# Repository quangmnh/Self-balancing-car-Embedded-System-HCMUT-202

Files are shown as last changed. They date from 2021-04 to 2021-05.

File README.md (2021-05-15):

# Abstract

We are making a Self-balancing robot taking inspiration from Wouter Klop's project

https://gitlab.com/kloppertje/balancingrobot

# Weekly Plan

## Week 20

- Calculate:
  + Torque
  + MPU-6050 returned value processing  
  + Body balancing factor (Applied mechanics lul)
- State machine
- Re-design some body part (da battery case, may need to ask Mr.Vỹ)..
- Print :
  + Battery Case (for next week when we receive the battery pack)
- Source code:
  + Clean up Mr. Klop's source code
  + Modularize them for easier report effort
- Hopefully make it run for da first time

## Week 19

- Calculation
  + Torque
  + MPU-6050 returned value processing  
  + Body balancing factor (Applied mechanics lul)
  + ~~Battery consumpstion and motor performance~~
- State machine 
- Re-design some body part (da battery case, may need to ask Mr.Vỹ).
- ~~Get PCB and assemble all parts ~~
- Print :
  + ~~Frame~~
  + ~~Wheel~~
  + Battery Case (for next week when we receive the battery pack)

## Week 16

- Calculation
  + Torque
  + MPU-6050 returned value processing  
  + Body balancing factor (Applied mechanics lul)
- State machine
- Re-design some body part.
- Get PCB and assemble all parts 
- Initiate the report.

## Week 15

- ~~Prototyping some body part for experiment.~~
- ~~Enlisting full electrical components with their price tag.~~
- ~~Buy the electrical components~~
- Initial calculation
  + Torque
  + ~~Power consumption~~
  + MPU-6050 returned value processing  
  + Body balancing factor (Applied mechanics lul)
- Re-design some body part.
- ~~PCB order (JLCPCB maybe)~~

# Expenditure and Notes

https://docs.google.com/spreadsheets/d/1sYImMAOnU2ea2EhUiEneGWEZ3-_E23mFMH0feFGn73Y/edit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

# Contents

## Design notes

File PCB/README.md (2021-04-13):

This folder contains KiCad (5.0.0) design files for the BalancingRobot PCB. 

# Features
* Supports both DRV8825 and A4988 based stepper drivers. Should also be compatible with TMC2100 (with settings configurable via ESP32), not tested yet though.
* Supported voltage: ~7 - 24V (2-6S LiPo/Li-ion)
* Digital current control of steppers (you'll need to desolder the potmeter and add a wire)
* Dynamic microstep switching, allowing for insane speeds
* Connections: 
	- Digital RC receiver (I use IBus / FlySky protocol), J5 upper row
	- Servo, J5 middle row. In case you want to add an arm for self righting :).
	- Digital LED (Neopixel / WS2812B etc), J5, lower row
	- All unused ESP32 pins are broken out (including I2C), for further use and development (J2)
	- Power input (J3). Allows for both a screw clamp and direct wire soldering. I prefer the last, given the high power output of a LiPo in case something comes loose.
* Wireless parameter tuning and data plotting. Makes tuning the controllers a lot easier
* Websocket communication for real-time communication between ESP32 and browser
* Web interface via access point / WiFi network. SSID and key can be set via web interface.

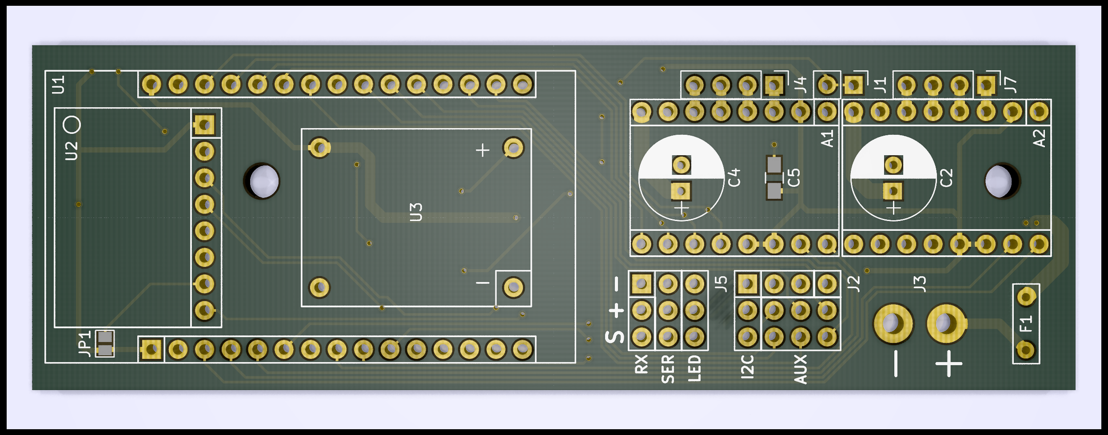
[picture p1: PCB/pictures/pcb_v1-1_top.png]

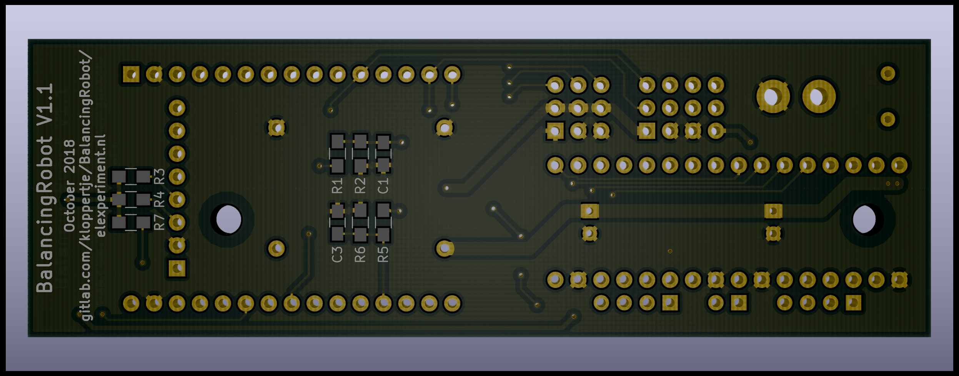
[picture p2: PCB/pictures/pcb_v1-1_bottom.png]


# Assembly
Assembly is quite straightforward. For those who like some instructions, here goes. For the ones that don't like to follow instructions: that's ok, but please read the last instruction about adjusting the buck converter voltage.

1. Start with the SMD components on the bottom side. First, pre-tin one pad, then place the SMD component while reheating the first pad. Finally, solder the second pad. C5 is not mounted.
2. Next, mount the voltage regulator module U3. Use some wires to connect the 4 pads to the PCB.
3. Place the IMU (U2) with the angled male and female headers. Make sure that the IMU is rigidly mounted. If you don't, the IMU might for example vibrate during operation, causing unstable behaviour. See below pictures for clarification.
4. Add all female headers (J1, J4, J7, and for the stepper driver and ESP32 modules). Optionally, place some headers on J5 and J2 if you like.
5. Finally, place C2, C4 and F1.

IMPORTANT: adjust the voltage regulator to 5V BEFORE inserting any modules. By default, the voltage regulator is set to a higher voltage, and if you don't adjust it, you'll fry some components. 

IMU mounting
<p float="left">
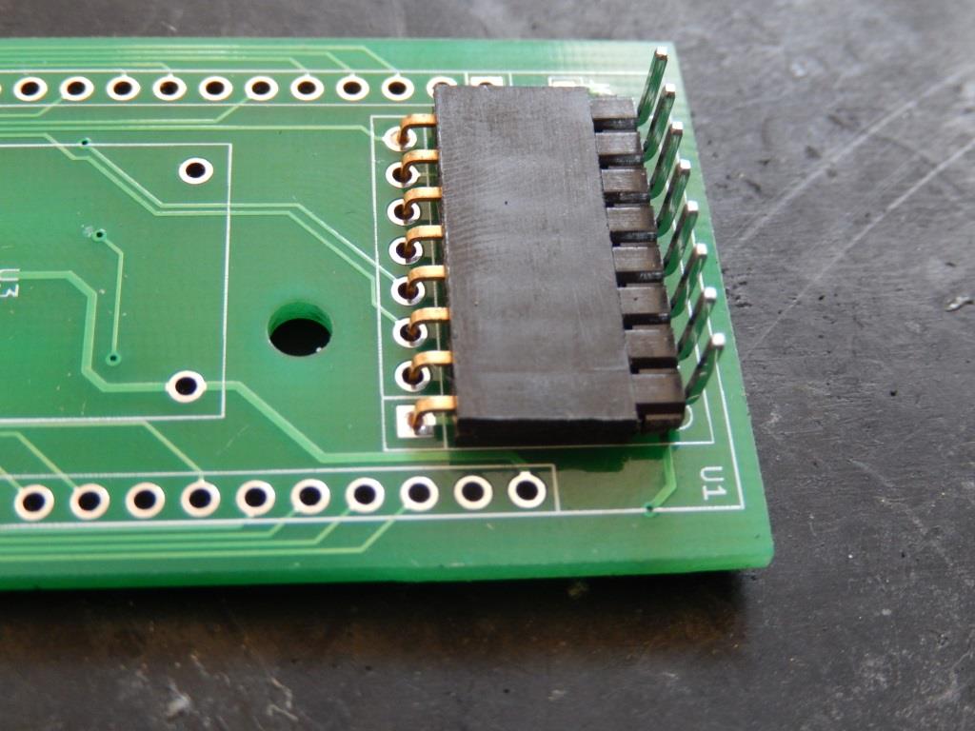
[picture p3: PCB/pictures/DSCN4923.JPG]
  
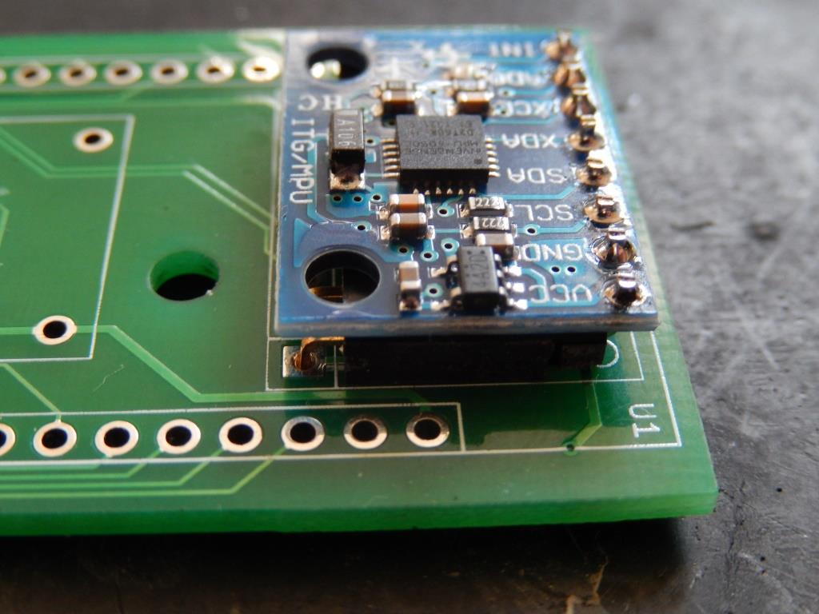
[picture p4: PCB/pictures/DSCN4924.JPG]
   
</p>

In the end, the PCB should look something like this
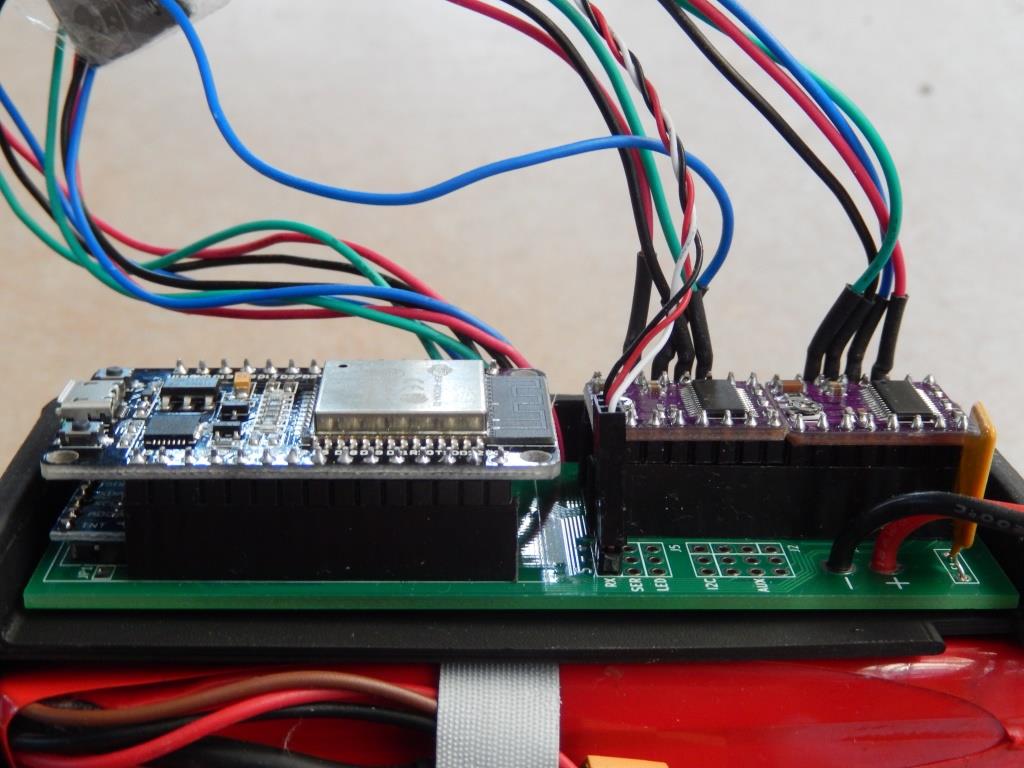
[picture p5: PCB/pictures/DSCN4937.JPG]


## Advanced
Some optional improvements are listed here, which are not required for basic operation. 

You can de-solder the current adjustment potentiometer on the stepper driver breakout boards. Add a wire to the wiper terminal, and connect the (two) wires to J4. Current can then be adjusted via the web interface. Or, get creative, and implement some current saving functionality.

For better performance, you can tie the decay mode pin of the DRV8825 to VCC, setting it in fast mode. The DRV8825 sometimes skips steps in slow/mixed decay mode. Below picture illustrates both improvements.

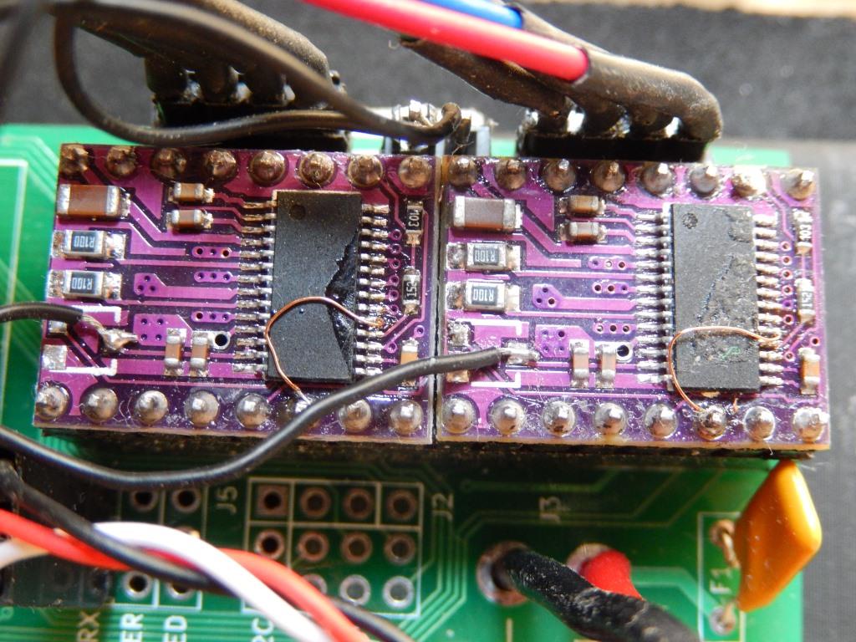
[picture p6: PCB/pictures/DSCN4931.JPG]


## Auxiliary header
Connector J2 has a grid of 12 pins (3x4), with some general pins broken out, together with all unused ESP32 IO pins. See the close-up of the header below. Pin numbering in this picture is used in the table below to identify pins.

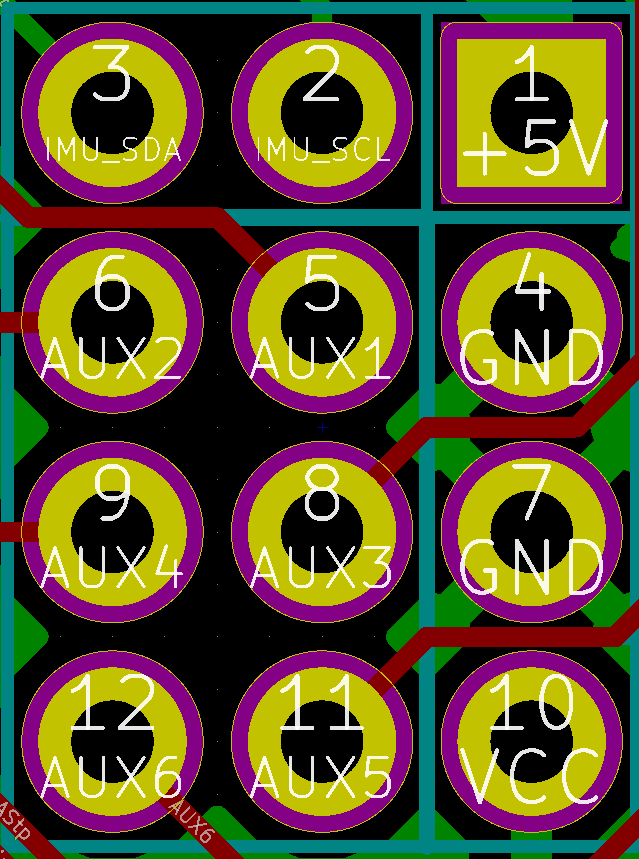
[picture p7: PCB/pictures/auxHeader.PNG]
Auxiliary header pinout
//


| Pin # | Name | ESP32 pin |
|---|---|---|
| 1 | 5V | Vin |
| 2 | IMU_SCL | D22 |
| 3 | IMU_SDA | D21 |
| 4 | GND | GND |
| 5 | AUX1 | D32 |
| 6 | AUX2 | D33 |
| 7 | GND | GND |
| 8 | AUX3 | D35 |
| 9 | AUX4 | D26 |
| 10 | VCC | 3V3 |
| 11 | AUX5 | D39 |
| 12 | AUX6 | D36 |

# BOM
Applicable for v1.1. v1.0 doesn't have R7.

| Qty | Reference(s) | Value |
|-----|---|---|
| 2 | A1, A2 | DRV8825 / A4988 stepper driver breakout  |
| 2 | C1, C3 | 1u capacitor, 0805 SMD |
| 2 | C2, C4 | 100u elco |
| 1 | C5 | 100n capacitor, not placed |
| 1 | F1 | Polyfuse |
| 1 | J1 | Female header, cut to size |
| 1 | J2 | N/A, solder whatever you like here |
| 1 | J3 | Screw terminal, or solder wires directly |
| 2 | J4, J7 | 4 pin (fe)male header, cut to size |
| 1 | J5 | Male header, cut to size |
| 6 | R1, R2, R3, R4, R6, R7 | 3k3 resistor, 0805 SMD |
| 1 | R5 | 100k resistor, 0805 SMD |
| 1 | U1 | ESP32 devKit module, 30 pins |
| 1 | U2 | MPU6050 breakout, 8 pins |
| 1 | U3 | Buck converter module |

Additionally, you'll need a pair of 8 pin male/female angled headers, for mounting the IMU. For mounting the ESP32 and stepper driver modules, you'll need 2 times 15 and 16 pin female headers (4 in total).

Some examples of the modules:
* [ESP32 Devkit V1 module, 30 pins](https://www.aliexpress.com/item/ESP32-Development-Board-WiFi-Bluetooth-Ultra-Low-Power-Consumption-Dual-Core-ESP-32-ESP-32S/32802431728.html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)
* [DRV8825 stepper driver](https://www.aliexpress.com/item/Free-shipping-10pcs-lot-3D-Printer-StepStick-DRV8825-Stepper-Motor-Drive-Carrier-Reprap-4-layer-PCB/32292074706.html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)
* [MPU6050 IMU](http://www.aliexpress.com/item/GY-521-MPU-6050-MPU6050-Module-3-Axis-analog-gyro-sensors-3-Axis-Accelerometer-Module/32340949017.html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)
* [Buck converter](https://www.aliexpress.com/item/10PCS-Mini-3A-DC-DC-Converter-Step-Down-Module-Adjustable-3V-5V-16V-Power-for-RC/32639738406.html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)

# Issues
For PCB version 1.0, the + and - signs of the RX/Servo/LED indicator are swapped. The pinout is correct though. To be clear, the order (from right to left) is -, +, and signal. This has been solved in v1.1.

# Change history
## v1.0 
Initial version
## v1.1
* Increased track width of 5V and 24V traces
* Added second via in 24V trace, or rather added trace to second via which wasn't there in v1.0
* Swapped + and - symbols on silkscreen close to RX header 
* Added a 10k pull-up on the stepper driver enable. In v1.0, no pull-up is present, meaning the steppers are enabled if the ESP32 isn't running. No big deal, but somewhat neater to disable steppers if the ESP32 isn't running.
## v1.2
* Added optional 100k RX pulldown resistor
* Added optional 5V filtering cap (might be useful if for example some Neopixels are connected to 5V line)
* Added some markings for the buck converter, clarifying the mounting direction
* Added connections for (fused) battery voltage (J6)

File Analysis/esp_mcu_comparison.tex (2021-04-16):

\documentclass[tikz,table,border=2mm]{standalone}
\usepackage{PTSansNarrow}
\usepackage[T1]{fontenc}
\usepackage{array,tabularx}
\usepackage[most]{tcolorbox}

\begin{document}

\rowcolors{1}{black!30}{white}
\begin{tcolorbox}[enhanced, notitle, clip upper, fontupper=\sffamily,%
    tabularx={>{\cellcolor[gray]{.5}\color{white}}r%
              >{\centering\arraybackslash}X%
              >{\centering\arraybackslash}X}]
Aspect  & NodeMCU wroom     & ESP32 wrover \\
Size     & 25.4*48.26*3mm( 0.2mm ) & 18.00±0.10)×(31.40±0.10)×(3.30±0.10) \\
Interface       & FC-4                               & PCIe x4 \\
Drive Units     & 150$\times$15 RPM disks            & 2$\times$80gig\\
Data Protection & Mirroring                          & Mirroring\\
Power           & 33.372 kWh/yr                      & 114 kWh/yr\\
SPC-1 I0PS      & 24.998                             & 86.127
\end{tcolorbox}
\end{document}

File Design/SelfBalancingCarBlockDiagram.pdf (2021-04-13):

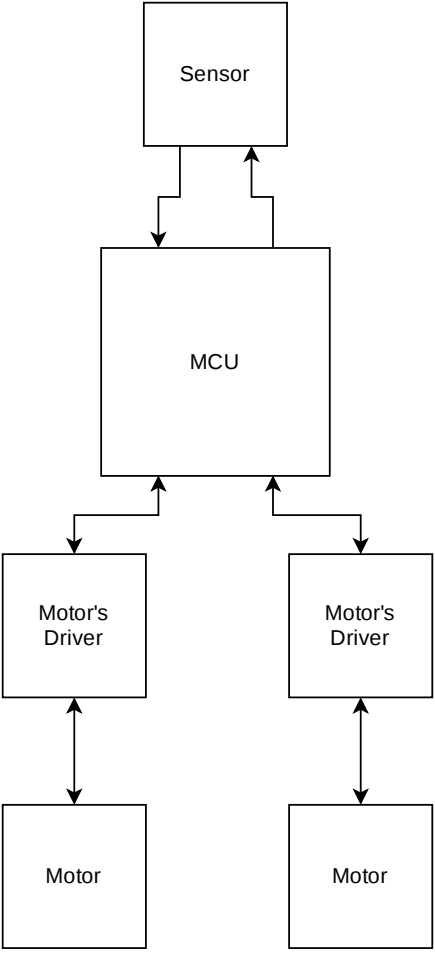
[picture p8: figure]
MCU; Motor; Motor's Driver; Sensor

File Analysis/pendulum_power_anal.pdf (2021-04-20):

VIETNAM NATIONAL UNIVERSITY - HO CHI MINH CITY UNIVERSITY OF TECHNOLOGY
FACULTY OF COMPUTER SCIENCE & ENGINEERING

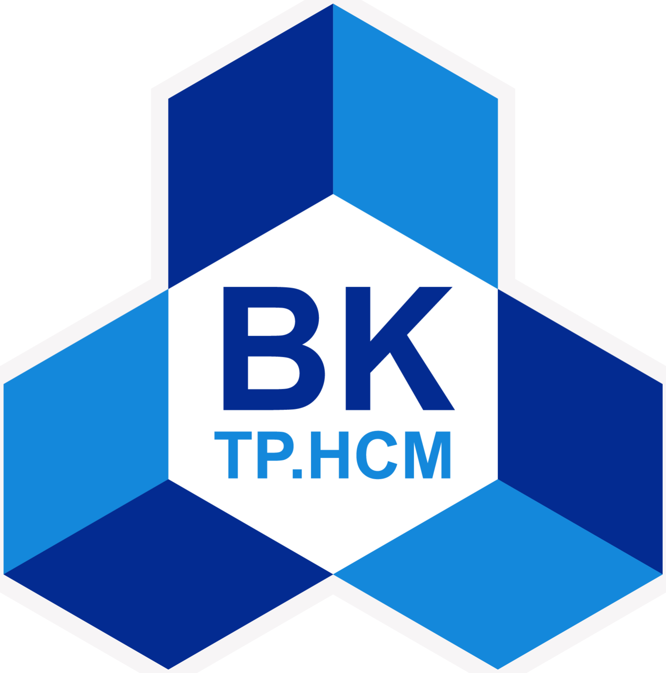
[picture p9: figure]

## EMBEDDED SYSTEM

## Analysis

# POWER & PERFORMANCE

Instructor: | Pham Hoang Anh
Student: | Nguyen Tran Quang Minh | - 1811083

HO CHI MINH CITY, April 2021

Ho Chi Minh City University of Technology Faculty of Computer Science & Engineering

## Contents

1 Power | 2
Embedded System - 2020-2021 | Page 1/3

## 1 Power

### 1.1 Datasheet information:

No. | Name | Description | Min | Max | Typical | Note
1. | ESP32 de-vkit | The operating voltage of ESP32 ranges from 2.3 V to 3.6 V. When using a single-power supply, the recommended volt-age of the power supply is 3.3 V | 500 mA | - | - | Average current in actual test is no more than 150 mA with 600 mA spike
2. | MPU6050 | The sensor has 3 dis-tinct feature and power consumption is based on what features are used in combination Gyroscope/Accelerome-ter/DMP | 3.6 mA | 3.9 mA | 3.6 mA | Look like only Gy-roscope is used
3. | Nema 17 | The motor operates in 2 phase, with rated voltage and currentin the datasheet, model KH42JM2B182A | 0.85 A | 0.9 A | 0.88 A | The stats in official datasheet and product mark is different so i take them as low/high values.

### 1.2 Calculation:

With the above stats, we can assume that the pair of motor will draw 0.88*2 =1.76 A per phase

and 3.52 A in total.

Therefore, we need about 4A current (at max) and about 3.7 A average. The battery we chose,

a 3-cell Lion battery with 30 C max discharge current and 2000 mAh capacity, merely meets the requirement. We expect it to sustain at least half an hour before recharge.

With some calculation, we can get the maximum performance of the Nema 17 stepper motor [1]:

M axSpeed =

V
2LImax · spr

(1)

M intimeperstep =

2LImax
V

(2)

Pmax = ImaxV | (3)

Hence, at nominal voltage (3.7*3 = 11.1 V), we get the result of 6.18 revolutions/s, 0.809 ms/step

and 9.77 W max power.

At max voltrage (4.2*3 = 12.6 V), we get 7.02 revolutions/s, 0.712 ms/step and 11.1 W max

power.

## References

[1] https://www.allaboutcircuits.com/tools/stepper-motor-calculator/

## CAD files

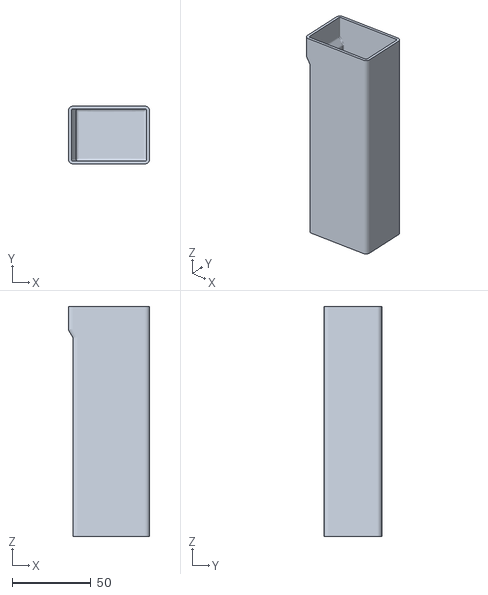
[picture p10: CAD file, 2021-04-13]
3dpart/battery-case/BatteryCase v1.stl
51.8 x 36.8 x 146.5

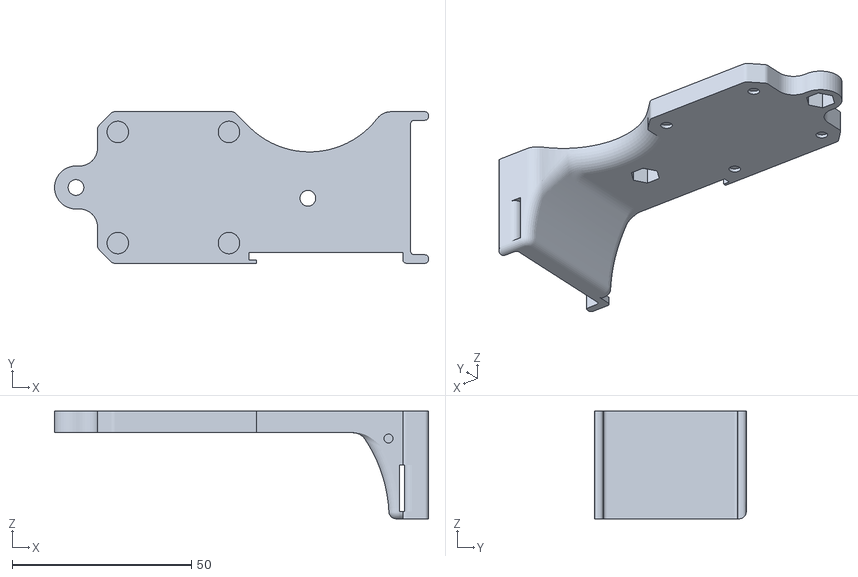
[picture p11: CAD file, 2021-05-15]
3dpart/frame/frameA1_mirror.stl
104.3 x 42.3 x 30.0

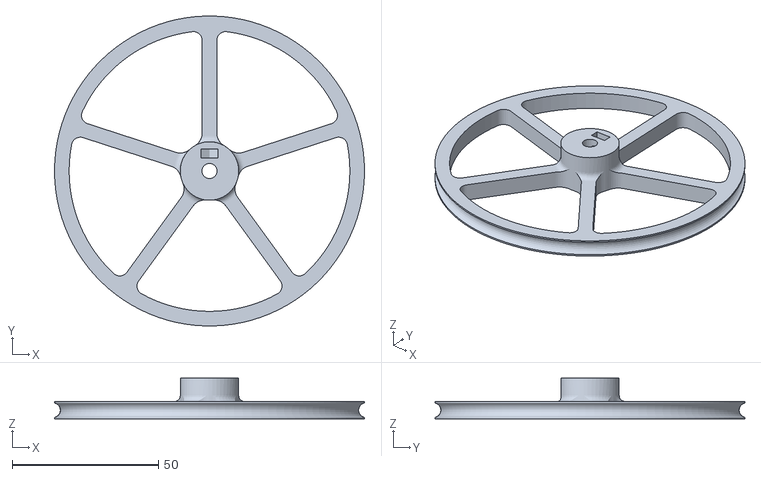
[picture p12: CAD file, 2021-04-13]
3dpart/wheel/Wheel v2.stl
106.0 x 105.9 x 14.0

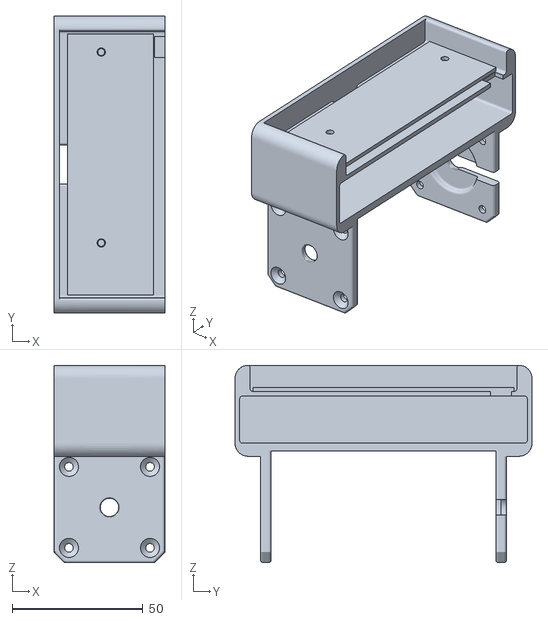
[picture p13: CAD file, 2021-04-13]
3dpart/frame/FrameB v10.stl
42.3 x 113.6 x 75.5

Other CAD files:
3dpart/frame/FrameA1.stl
3dpart/frame/FrameA2.stl
3dpart/battery-case/BatteryCase v1.f3d
3dpart/frame/FrameA v1.f3d
3dpart/frame/FrameB v10.f3d
3dpart/untitled.blend
3dpart/wheel/Wheel v2.f3d

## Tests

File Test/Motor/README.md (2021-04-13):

This folder contains the software source files, written for an ESP32 using the Arduino framework. PlatformIO is used as environment, as it is very easy to use, and provides somewhat more advanced functions, compared to the very basic Arduino IDE. 

# Build environment
For setting up PlatformIO, see https://docs.platformio.org/en/latest/ide/atom.html or https://docs.platformio.org/en/latest/ide/vscode.html. I use Atom myself, but both IDEs will work fine. 

Clone the repository. I strongly advice to not download the source files as a zip package, but to use Git properly. The code is very experimental, and will be often updated.

Once installed, go to PlatformIO home in the IDE. In there, click "Open Project", and navigate to the location where you cloned the repository. Select the "Software" folder, and then click "Open "Software"". 

Open src/main.cpp. You should now be able to combile (ctrl+alt+B).

# Uploading firmware
For uploading, I strongly prefer OTA, as this works very nice in PlatformIO.  

## Serial port
For the first upload, you'll need to upload via USB / the serial port. In platformio.ini, state the COM port under which the ESP32 module is connected (uncomment the line with an IP address / host name), for example 
upload_port = COM3. 
; upload_port = balancingRobot.local

Hit the upload button. Currently, the auto reset functionality of the ESP32 module doesn't seem to work, see Issue #10. So, once the message "Serial port COMx" appears, press the enable and boot buttons on the module. First release the boot button, then the enable button. You might have to try a few times. Luckily, once succeeded with the serial upload, you can use OTA upload.

## OTA upload
When the ESP32 boots, it's IP address is printed. In platformio.ini, fill in this IP address under upload_port. Or, even better, use the hostname balancingRobot.local. This means you don't have to mess around with IP addresses. Make sure to be connected to the same WiFi network as the ESP32, and hit upload.

## File system
Initially, or when changing the web page files, you need to upload the file system. To do so, open a terminal within the PlatformIO environment, and run:
platformio run --target uploadfs

This will upload all content of the data folder to the ESP32 flash memory (either via the serial port or OTA).

# WiFi connection
After flashing, the ESP32 will start an access point (AP), named balancingRobot. The default key is "turboturbo". Once connected, open the balancingRobot web configuration page. Here, among others, you can change the WiFi options. Under "WiFi configuration", enter the SSID and key of your home network, change the selector from "AP" to "SSID", and click the "set" button, followed by the "reboot" button. If all goes well, the ESP32 will now connect to your home network. 

If you are using an IP address instead of host name, don't forget to check the ESP32's IP address, and update this in platformio.ini. It is probably wise to assign a fixed IP address to the ESP32 (via the router).

If the home network cannot be found, the AP will be started.

# Web page editor
hostName.local/edit

User/pass: admin, admin

Be aware though that changes here are not kept on your PC, so make sure to copy and paste everything.

# Plotting signals
hostName.local/plotTest.htm

To be merged into index.htm

For this to work, first load plotTest.htm, then index.htm. This allows to view signals, while simultaneously adjusting parameters. 

# Wifi control
For a slider based web page to control your robot

hostName.local/control.htm

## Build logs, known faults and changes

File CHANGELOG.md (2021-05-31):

## [0.0.5] - 2021-05-15

### Added
- Test project for individual motor test (seem to be not working at 11.1 volts input), at
> test/Motor
- mirrored stl of frameA1_mirror.stl at 
> 3dpart/frame
- GCODE files for printing at ABC Solutions, at
> 3dpart/GCODE

## [0.0.4] - 2021-04-20

### Nice
### Added
- Power and performance analysis (to be updated). 

## [0.0.3] - 2021-04-16

### Added

- PCB gerber files for PCB order.
- x3g for printing body part.

## [0.0.2] - 2021-04-15

### Added

- Analysis folder initiated, comparison of ESP MCUs.

## [0.0.1] - 2021-04-13

### Added

- Hardware design as stl files, for 3d printed.
- PCB design using KiCAD
- Initial code for programming the development board.
- The block diagram of the system

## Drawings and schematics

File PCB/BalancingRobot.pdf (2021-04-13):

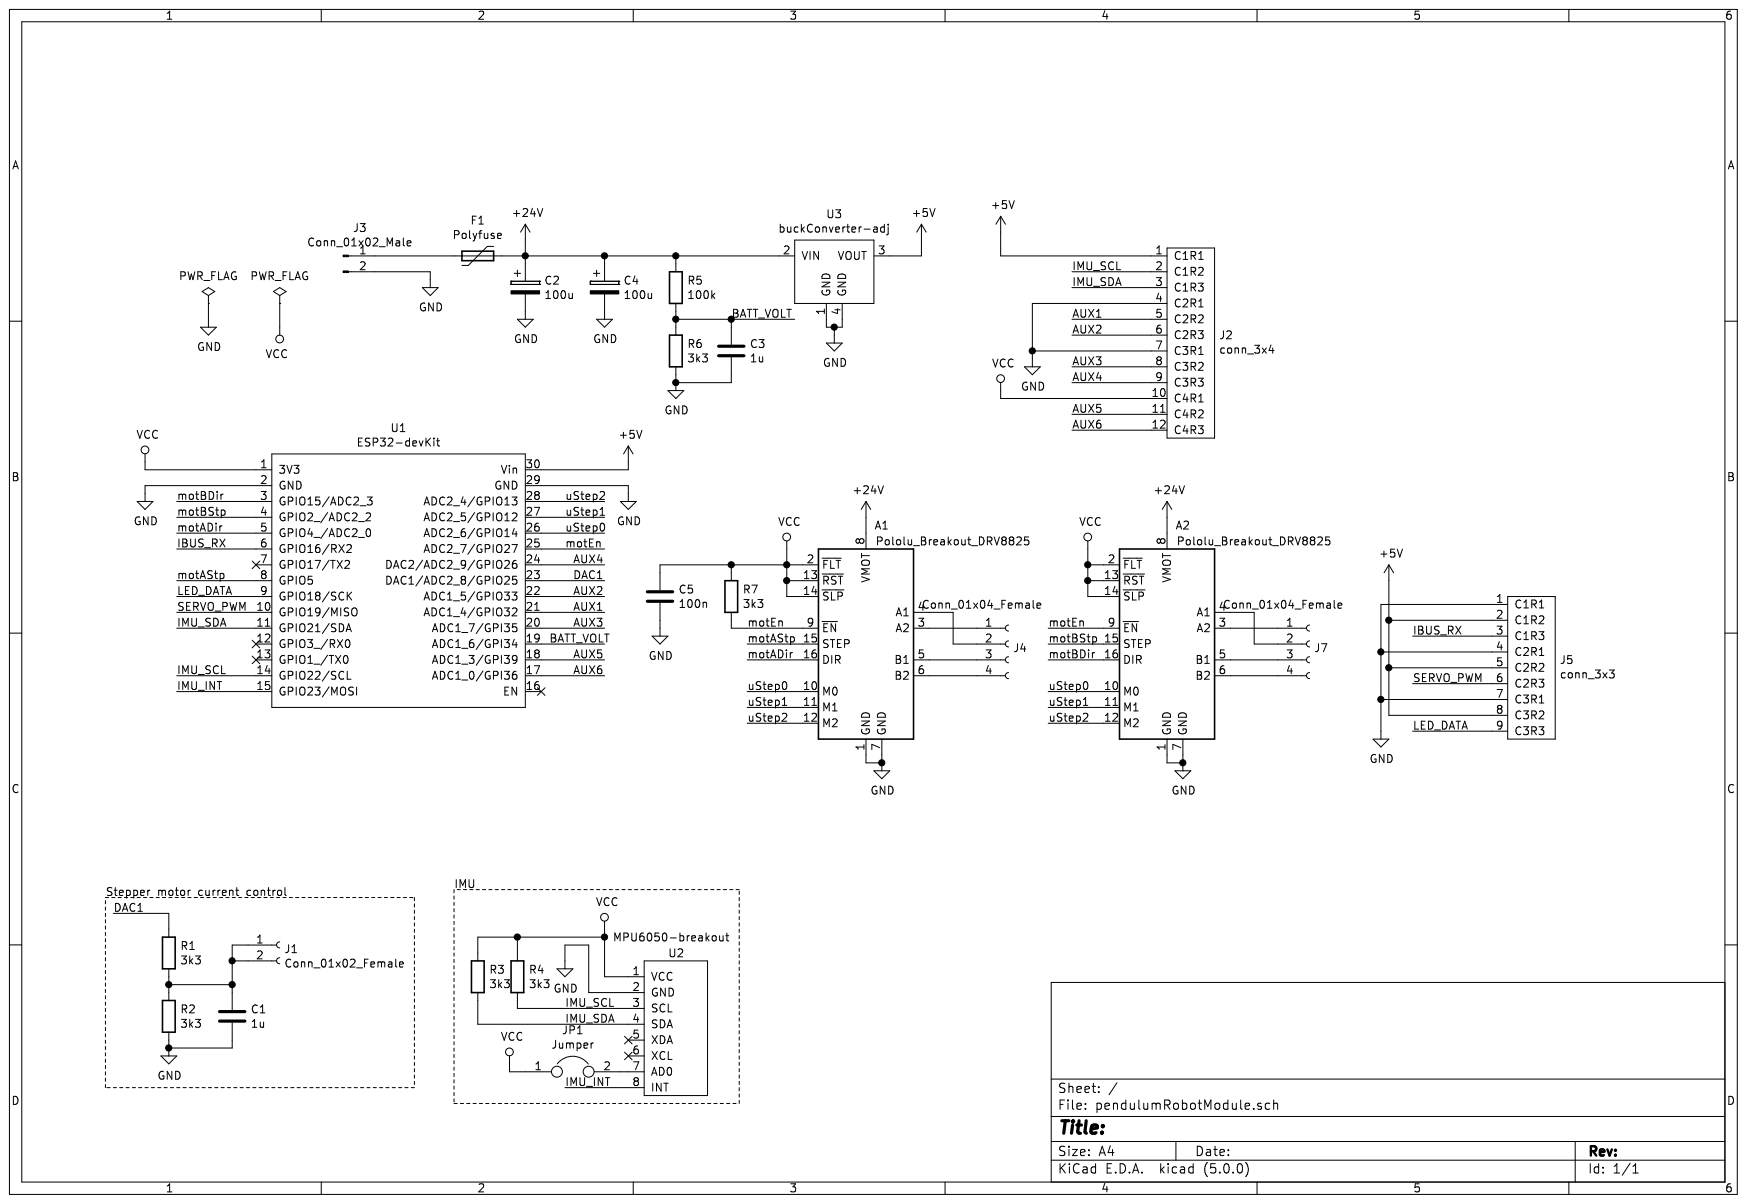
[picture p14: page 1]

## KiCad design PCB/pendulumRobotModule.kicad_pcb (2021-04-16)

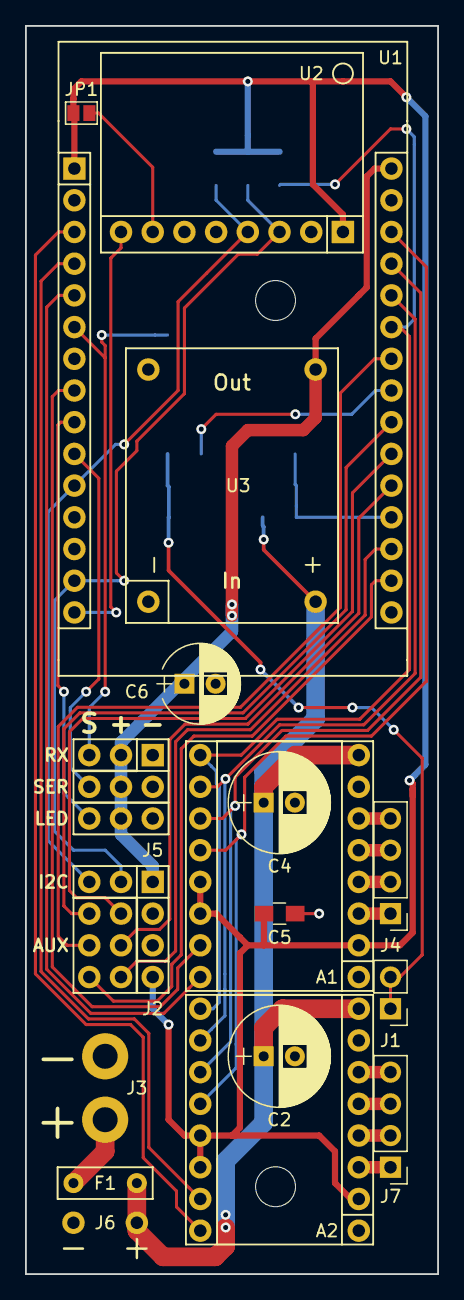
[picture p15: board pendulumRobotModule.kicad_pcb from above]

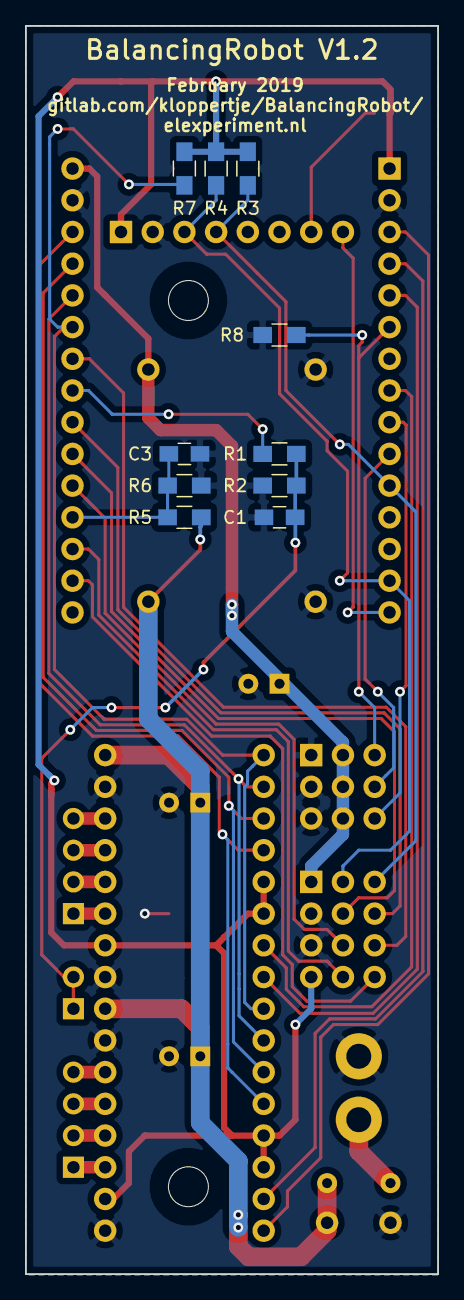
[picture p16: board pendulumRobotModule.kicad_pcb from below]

Board: 2 copper layers, 33.0 x 100.0 mm, 28 parts (10 on the bottom side), 37 nets.

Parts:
A1, A2: Pololu_Breakout_DRV8825; DRV8825-breakout
C1, C3: 1u; C_0805_HandSoldering
C2, C4: 100u; CP_Radial_D8.0mm_P2.50mm
C5: 100n; C_0805_HandSoldering
C6: 470u; CP_Radial_D6.3mm_P2.50mm
F1: Polyfuse; polyfuse-5.08mm
J1: Conn_01x02_Female; Socket_Strip_Straight_1x02_Pitch2.54mm
J2: conn_3x4; pinHeader_3x4
J3: Conn_01x02_Male; wirePad-2x-2mm
J4, J7: Conn_01x04_Female; Socket_Strip_Straight_1x04_Pitch2.54mm
J5: conn_3x3; pinHeader_3x3
J6: Conn_01x02_Male; pinHeader_2x1_5.08mm
JP1: Jumper; GS2
R1, R2, R3, R4, R6, R7: 3k3; R_0805_HandSoldering
R5, R8: 100k; R_0805_HandSoldering
U1: ESP32-devKit; ESP32-devkit-30p
U2: MPU6050-breakout; MPU6050-breakout-angledHeader
U3: buckConverter-adj; buck-converter-adj

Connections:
+5V: C6.1, J2.1, J5.2, J5.5, J5.8, U1.30, U3.3
+24V: A1.8, A2.8, C2.1, C4.1, F1.1, J6.1, R5.1, U3.2
/AUX1: J2.5, U1.21
/AUX2: J2.6, U1.22
/AUX3: J2.8, U1.20
/AUX4: J2.9, U1.24
/AUX5: J2.11, U1.18
/AUX6: J2.12, U1.17
/BATT_VOLT: C3.1, R5.2, R6.1, U1.19
/DAC1: R1.1, U1.23
/IBUS_RX: J5.3, R8.1, U1.6
/IMU_INT: U1.15, U2.8
/IMU_SCL: J2.2, R4.2, U1.14, U2.3
/IMU_SDA: J2.3, R3.2, U1.11, U2.4
/LED_DATA: J5.9, U1.9
/SERVO_PWM: J5.6, U1.10
/motADir: A1.16, U1.5
/motAStp: A1.15, U1.8
/motBDir: A2.16, U1.3
/motBStp: A2.15, U1.4
/motEn: A1.9, A2.9, R7.2, U1.25
/uStep0: A1.10, A2.10, U1.26
/uStep1: A1.11, A2.11, U1.27
/uStep2: A1.12, A2.12, U1.28
GND: A1.1, A1.7, A2.1, A2.7, C1.2, C2.2, C3.2, C4.2, C5.2, C6.2, J2.4, J2.7, J3.2, J5.1, J5.4, J5.7, J6.2, R2.2, R6.2, R8.2, U1.2, U1.29, U2.2, U3.1, U3.4
unnamed: A1.3, J4.1
unnamed: A1.4, J4.2
unnamed: A1.5, J4.3
unnamed: A1.6, J4.4
unnamed: A2.3, J7.1
unnamed: A2.4, J7.2
unnamed: A2.5, J7.3
unnamed: A2.6, J7.4
unnamed: C1.1, J1.1, J1.2, R1.2, R2.1
unnamed: F1.2, J3.1
unnamed: JP1.2, U2.7
VCC: A1.2, A1.13, A1.14, A2.2, A2.13, A2.14, C5.1, J2.10, JP1.1, R3.1, R4.1, R7.1, U1.1, U2.1

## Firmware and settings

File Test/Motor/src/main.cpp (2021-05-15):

/*
A high speed balancing robot, running on an ESP32.

Wouter Klop
wouter@elexperiment.nl
For updates, see elexperiment.nl

Use at your own risk. This code is far from stable.

This work is licensed under the Creative Commons Attribution-ShareAlike 4.0 International License.
To view a copy of this license, visit http://creativecommons.org/licenses/by-sa/4.0/
This basically means: if you use my code, acknowledge it.
Also, you have to publish all modifications.

*/
#include <Arduino.h>
#include <FlySkyIBus.h>
#include <WiFi.h>
#include <ESPmDNS.h>
#include <WiFiUdp.h>
#include <ArduinoOTA.h>
#include <Streaming.h>
#include <MPU6050.h>
#include <PID.h>
#include <AsyncTCP.h>
#include <ESPAsyncWebServer.h>
#include <WebSocketsServer.h>
#include <FS.h>
#include <SPIFFS.h>
#include <SPIFFSEditor.h>
#include <fastStepper.h>
// #include <par.h>
#include <Preferences.h>  // for storing settings

// Define parameter
#ifndef M_PI
  #define M_PI 3.14159265358979323846
#endif

// Define state variable
#define RUNNING 1
#define STANDBY 0
bool state = STANDBY;
// ----- Input method

// Driving behaviour
float speedFactor = 0.5;  // how strong it reacts to inputs, lower = softer (limits max speed) (between 0 and 1)
float steerFactor = 1.0;  // how strong it reacts to inputs, lower = softer (limits max speed) (between 0 and 1)
float speedFilterConstant = 0.9;  // how fast it reacts to inputs, higher = softer (between 0 and 1, but not 0 or 1)
float steerFilterConstant = 0.9;  // how fast it reacts to inputs, higher = softer (between 0 and 1, but not 0 or 1)

// PPM (called CPPM, PPM-SUM) signal containing 8 RC-Channels in 1 PIN ("RX" on board)
// Channel 1 = steer, Channel 2 = speed
#define INPUT_PPM
#define PPM_PIN 16  // GPIO-Number
#define minPPM 990  // minimum PPM-Value (Stick down)
#define maxPPM 2015  // maximum PPM-Value (Stick up)

// FlySkyIBus signal containing 8 RC-Channels in 1 PIN ("RX" on board)
// #define INPUT_IBUS

// ----- Type definitions
typedef union {
  struct {
    float val; // Float (4 bytes) comes first, as otherwise padding will be applied
    uint8_t cmd;
    uint8_t checksum;
  };
  uint8_t array[6];
} command;

// Plot settings
struct {
  boolean enable = 0; // Enable sending data
  uint8_t prescaler = 4;
} plot;

#define FORMAT_SPIFFS_IF_FAILED true

// ----- Function prototypes
void sendWifiList(void);
void parseSerial();
void parseCommand(char* data, uint8_t length);
void calculateGyroOffset(uint8_t nSample);
void readSensor();
void initSensor(uint8_t n);
void setMicroStep(uint8_t uStep);
void webSocketEvent(uint8_t num, WStype_t type, uint8_t * payload, size_t length);
void sendConfigurationData(uint8_t num);

void IRAM_ATTR motLeftTimerFunction();
void IRAM_ATTR motRightTimerFunction();

// ----- Definitions and variables
// -- Web server
const char* http_username = "admin";
const char* http_password = "admin";
AsyncWebServer httpServer(80);
WebSocketsServer wsServer = WebSocketsServer(81);

// -- EEPROM
Preferences preferences;

// -- Stepper motors
#define motEnablePin 27
#define motUStepPin1 14
#define motUStepPin2 12
#define motUStepPin3 13

fastStepper motLeft(5, 4, 0, motLeftTimerFunction);
fastStepper motRight(2, 15, 1, motRightTimerFunction);

uint8_t microStep = 32;
uint8_t motorCurrent = 150;
float maxStepSpeed = 1500;

// -- PID control
#define dT_MICROSECONDS 5000
#define dT dT_MICROSECONDS/1000000.0

#define PID_ANGLE 0
#define PID_POS 1
#define PID_SPEED 2

#define PID_ANGLE_MAX 20
PID pidAngle(cPD, dT, PID_ANGLE_MAX, -PID_ANGLE_MAX);
#define PID_POS_MAX 35
PID pidPos(cPD, dT, PID_POS_MAX, -PID_POS_MAX);
PID pidSpeed(cP, dT, PID_POS_MAX, -PID_POS_MAX);

uint8_t controlMode = 1; // 0 = only angle, 1 = angle+position, 2 = angle+speed

// -- IMU
MPU6050 imu;

#define GYRO_SENSITIVITY 65.5

int16_t gyroOffset[3];
float accAngle = 0;
float filterAngle = 0;
float angleOffset = 2.0;
float gyroFilterConstant = 0.996;
float gyroGain = 1.0;

// -- Others
#define ledPin 2
#define motorCurrentPin 25
#define battVoltagePin 34

// -- WiFi
const char host[] = "balancingrobot";

// Noise source (for system identification)
boolean noiseSourceEnable = 0;
float noiseSourceAmplitude = 1;

// ----- Parameter definitions -----
// void updatePIDParameters() {
//   pidAngle.updateParameters();
//   pidSpeed.updateParameters();
//   pidPos.updateParameters();
// }
// par pidPar[] = {&pidAngle.K, &pidAngle.Ti, &pidAngle.Td, &pidAngle.N, &pidAngle.R, &pidAngle.minOutput, &pidAngle.maxOutput, &pidAngle.controllerType,
//   &pidPos.K, &pidPos.Ti, &pidPos.Td, &pidPos.N, &pidPos.R, &pidPos.minOutput, &pidPos.maxOutput, &pidPos.controllerType,
//   &pidSpeed.K, &pidSpeed.Ti, &pidSpeed.Td, &pidSpeed.N, &pidSpeed.R, &pidSpeed.minOutput, &pidSpeed.maxOutput, &pidSpeed.controllerType, &updatePIDParameters};
//
// parList pidParList(pidPar);

// par motorPar[] = {&motorCurrent, &maxStepSpeed};
// par wifiPar[] = {&wifiMode, &wifiSSID, &wifiKey};
// par sensorPar[] = {&gyroOffset, &gyroGain, &angleOffset, &updateGyroOffset, &updateAngleOffset};
// par controlPar[] = {&remoteType, &controlMode};

// struct {
//   struct {
//     uint8_t mode;
//     char ssid[30];
//     char key[30];
//   } wifi;
// } settings;

// ----- Interrupt functions -----
portMUX_TYPE timerMux = portMUX_INITIALIZER_UNLOCKED;

void IRAM_ATTR motLeftTimerFunction() {
  portENTER_CRITICAL_ISR(&timerMux);
  motLeft.timerFunction();
  portEXIT_CRITICAL_ISR(&timerMux);
}
void IRAM_ATTR motRightTimerFunction() {
  portENTER_CRITICAL_ISR(&timerMux);
  motRight.timerFunction();
  portEXIT_CRITICAL_ISR(&timerMux);
}


void setMotorCurrent() {
  dacWrite(motorCurrentPin, motorCurrent);
}

void sendData(uint8_t *b, uint8_t l) {
  wsServer.sendBIN(0,b,l);
}

void wirelessTask(void * parameters) {
  while (1) {
    #ifdef INPUT_IBUS
    IBus.loop();
    #endif
    wsServer.loop();
    delay(2);
  }
}

// -- PPM Input
#ifdef INPUT_PPM
volatile int interruptCounter = 0;
int numberOfInterrupts = 0;

// portMUX_TYPE mux = portMUX_INITIALIZER_UNLOCKED;

//Array in which the channel values are stored
volatile int32_t rxData[] = {0,0,0,0,0,0,0,0};
//int in which the time difference to the last pulse is stored
volatile uint32_t rxPre = 1;
//int in which the current channel number to read out is stored
volatile uint8_t channelNr = 0; 
//indicates if the data in the channel value array are reliable e.g. there have been two sync breaks, so in the array there are only "real" values synced to the correspondinc channel number
volatile uint8_t firstRoundCounter = 2;
volatile boolean firstRoundPassed = false;
volatile boolean validRxValues = false;

void rxFalling() {  // will be called when the ppm peak is over
  if(micros()-rxPre > 6000) {  // if the current peak is the first peak after the syncro break of 10ms
    rxPre = micros();
    channelNr = 0;  // reset the channel number to syncronize again
    firstRoundCounter--;//the values in the first round are complete rubish, since there would'nt have been a first channel sync, this var indicates for the other functions, if the values are reliable
    if(firstRoundCounter == 0) firstRoundPassed = true;
  }
  else {
    rxData[channelNr] = micros()-rxPre;
    rxPre = micros();
    channelNr++;
  } 
  if(!validRxValues) {
    if(firstRoundPassed) {
        validRxValues = true;
    }
  }
}
#endif

// ----- Main code
void setup() {

  pinMode(motEnablePin, OUTPUT);
  pinMode(motUStepPin1, OUTPUT);
  pinMode(motUStepPin2, OUTPUT);
  pinMode(motUStepPin3, OUTPUT);
  digitalWrite(motEnablePin, 1); // Disable steppers during startup
  setMicroStep(microStep);

  pinMode(ledPin, OUTPUT);
  digitalWrite(ledPin, 0);

  motLeft.init();
  motRight.init();
  motLeft.microStep = microStep;
  motRight.microStep = microStep;

 

}

float steerInput, speedInput;

float mapfloat(float x, float in_min, float in_max, float out_min, float out_max)
{
 return (x - in_min) * (out_max - out_min) / (in_max - in_min) + out_min;
}

// Define variable for the process
static unsigned long tLast = 0;
float pidAngleOutput = 0;
float avgMotSpeed;
float steer = 0;
static float avgSteer;
static float avgSpeed;
static boolean enableControl = 0;
static float avgMotSpeedSum = 0;
int32_t avgMotStep;
float pidPosOutput = 0, pidSpeedOutput = 0;
static uint8_t k = 0;
static float avgBatteryVoltage = 0;
static uint32_t lastInputTime = 0;
uint32_t tNowMs;
float absSpeed = 0;
float noiseValue = 0;

void running() {
  // Read receiver inputs

  #ifdef INPUT_IBUS
    if (IBus.isActive())
    {                                                                       // Check if receiver is active
      speedInput = ((float)IBus.readChannel(1) - 1500) / 5.0 * speedFactor; // Normalise between -100 and 100
      steerInput = ((float)IBus.readChannel(0) - 1500) / 5.0 * steerFactor;
    }
  #endif

  #ifdef INPUT_PPM
    if (rxData[1] == 0 || rxData[0] == 0)
    { // no ppm signal (tx off || rx set to no signal in failsave || no reciever connected (use 100k pulldown))
      speedInput = 0.0;
      steerInput = 0.0;
    }
    else
    {                                                                                                                                // normal ppm signal
      speedInput = mapfloat((float)constrain(rxData[1], minPPM, maxPPM), (float)minPPM, (float)maxPPM, -100.0, 100.0) * speedFactor; // Normalise between -100 and 100
      steerInput = mapfloat((float)constrain(rxData[0], minPPM, maxPPM), (float)minPPM, (float)maxPPM, -100.0, 100.0) * steerFactor;
    }
  #endif

    avgSpeed = speedFilterConstant * avgSpeed + (1 - speedFilterConstant) * speedInput / 5.0;
    avgSteer = steerFilterConstant * avgSteer + (1 - steerFilterConstant) * steerInput;
    // uint8_t lastControlMode = controlMode;
    // controlMode = (2000-IBus.readChannel(5))/450;

    if (abs(avgSpeed) < 0.2)
    {
      // speedInput = 0;
    }
    else
    {
      lastInputTime = tNowMs;
      if (controlMode == 1)
      {
        controlMode = 2;
        motLeft.setStep(0);
        motRight.setStep(0);
        pidSpeed.reset();
      }
    }

    steer = avgSteer;
    // if (abs(avgSteer)>1) {
    //   steer = avgSteer * (1 - abs(avgSpeed)/150.0);
    // } else {
    //   steer = 0;
    // }

    // }

    if (tNowMs - lastInputTime > 2000 && controlMode == 2)
    {
      controlMode = 1;
      motLeft.setStep(0);
      motRight.setStep(0);
      pidPos.reset();
    }

    if (controlMode == 0)
    {
      pidAngle.setpoint = avgSpeed * 2;
    }
    else if (controlMode == 1)
    {
      avgMotStep = (motLeft.getStep() + motRight.getStep()) / 2;
      pidPos.setpoint = avgSpeed;
      pidPos.input = -((float)avgMotStep) / 1000.0;
      pidPosOutput = pidPos.calculate();
      pidAngle.setpoint = pidPosOutput;
    }
    else if (controlMode == 2)
    {
      pidSpeed.setpoint = avgSpeed;
      pidSpeed.input = -avgMotSpeedSum / 100.0;
      pidSpeedOutput = pidSpeed.calculate();
      pidAngle.setpoint = pidSpeedOutput;
    }

    // Optionally, add some noise to angle for system identification purposes
    // if (noiseSourceEnable) {
    //   pidAngle.input = filterAngle + noiseSourceAmplitude*((random(1000)/1000.0)-0.5);
    // } else {
    pidAngle.input = filterAngle;
    // }

    pidAngleOutput = pidAngle.calculate();

    if (noiseSourceEnable)
    {
      noiseValue = noiseSourceAmplitude * ((random(1000) / 1000.0) - 0.5);
      pidAngleOutput += noiseValue;
    }

    avgMotSpeedSum += pidAngleOutput / 2;
    if (avgMotSpeedSum > maxStepSpeed)
    {
      avgMotSpeedSum = maxStepSpeed;
    }
    else if (avgMotSpeedSum < -maxStepSpeed)
    {
      avgMotSpeedSum = -maxStepSpeed;
    }
    avgMotSpeed = avgMotSpeedSum;
    motLeft.speed = avgMotSpeed + steer;
    motRight.speed = avgMotSpeed - steer;

    // Switch microstepping
    absSpeed = abs(avgMotSpeed);
    uint8_t lastMicroStep = microStep;

    if (absSpeed > (150 * 32 / microStep) && microStep > 1)
      microStep /= 2;
    if (absSpeed < (130 * 32 / microStep) && microStep < 32)
      microStep *= 2;

    if (microStep != lastMicroStep)
    {
      motLeft.microStep = microStep;
      motRight.microStep = microStep;
      setMicroStep(microStep);
    }

    // Disable control if robot is almost horizontal. Re-enable if upright.
    if (abs(filterAngle) > 70)
    {
      enableControl = 0;
      motLeft.speed = 0;
      motRight.speed = 0;
      digitalWrite(motEnablePin, 1); // Inverted action on enable pin
    }
}

void reset() {
  if (abs(filterAngle) < 0.5)
  { // (re-)enable and reset stuff
    enableControl = 1;
    controlMode = 1;
    avgMotSpeedSum = 0;
    motLeft.setStep(0);
    motRight.setStep(0);
    pidAngle.reset();
    pidPos.reset();
    pidSpeed.reset();
    digitalWrite(motEnablePin, 0); // Inverted action on enable pin
    // delay(1);
  }
}
int count = 0;
void loop() {
/*
  static unsigned long tLast = 0;
  float pidAngleOutput = 0;
  float avgMotSpeed;
  float steer = 0;
  static float avgSteer;
  static float avgSpeed;
  static boolean enableControl = 0;
  static float avgMotSpeedSum = 0;1
  int32_t avgMotStep;
  float pidPosOutput = 0, pidSpeedOutput = 0;
  static uint8_t k = 0;
  static float avgBatteryVoltage = 0;
  static uint32_t lastInputTime = 0;
  uint32_t tNowMs;
  float absSpeed = 0;
  float noiseValue = 0;
*/

  unsigned long tNow = micros();
  tNowMs = millis();
  
  // checking the system every 0.005s
  if (tNow-tLast > 5000) {
    count = (count+1)%200;
    motLeft.setStep(count);
    motRight.setStep(count);
  }

}

void parseSerial() {
  static char serialBuf[10];
  static uint8_t pos = 0;
  char currentChar;

  while (Serial.available()) {
    currentChar = Serial.read();
    serialBuf[pos++] = currentChar;
    if (currentChar == 'x') {
      parseCommand(serialBuf, pos);
      pos = 0;
    }
  }

}

void parseCommand(char* data, uint8_t length) {
  float val2;
  if ((data[length-1]=='x') && length>=3) {
    switch (data[0]) {
      case 'c': { // Change controller parameter
        uint8_t controllerNumber = data[1] - '0';
        char cmd2 = data[2];
        float val = atof(data+3);

        // Make a temporary pid object, in which parameters are updated
        PID pidTemp = pidAngle;
        switch (controllerNumber) {
          case 1: pidTemp = pidAngle; break;
          case 2: pidTemp = pidPos;   break;
          case 3: pidTemp = pidSpeed; break;
        }

        switch (cmd2) {
          case 'p': pidTemp.K = val;  break;
          case 'i': pidTemp.Ti = val; break;
          case 'd': pidTemp.Td = val; break;
          case 'n': pidTemp.N = val; break;
          case 't': pidTemp.controllerType = (uint8_t) val; break;
          case 'm': pidTemp.maxOutput = val; break;
          case 'o': pidTemp.minOutput = -val; break;
        }
        pidTemp.updateParameters();

        // Store temporary pid object in correct pid object
        switch (controllerNumber) {
          case 1: pidAngle = pidTemp; break;
          case 2: pidPos = pidTemp;   break;
          case 3: pidSpeed = pidTemp; break;
        }

        Serial << controllerNumber << "\t" << pidTemp.K << "\t" << pidTemp.Ti << "\t" << pidTemp.Td << "\t" << pidTemp.N << "\t" << pidTemp.controllerType << endl;
        break;
      }
      case 'a': // Change angle offset
        angleOffset = atof(data+1);
        Serial << angleOffset << endl;
        break;
      case 'f':
        gyroFilterConstant = atof(data+1);
        Serial << gyroFilterConstant << endl;
        break;
      case 'v':
        motorCurrent = atof(data+1);
        Serial << motorCurrent << endl;
        dacWrite(motorCurrentPin, motorCurrent);
        break;
      case 'm':
        val2 = atof(data+1);
        Serial << val2 << endl;
        controlMode = val2;
        break;
      case 'u':
        microStep = atoi(data+1);
        setMicroStep(microStep);
        break;
      case 'g':
        gyroGain = atof(data+1);
        break;
      case 'p': {
        switch (data[1]) {
          case 'e':
            plot.enable = atoi(data+2);
            break;
          case 'p':
            plot.prescaler = atoi(data+2);
            break;
          case 'n': // Noise source enable
            noiseSourceEnable = atoi(data+2);
            break;
          case 'a': // Noise source amplitude
            noiseSourceAmplitude = atof(data+2);
            break;
        }
        break;
      }
      // case 'h':
      //   plot.enable = atoi(data+1);
      //   break;
      // case 'i':
      //   plot.prescaler = atoi(data+1);
      //   break;
      case 'j':
        gyroGain = atof(data+1);
        break;
      case 'k': {
        uint8_t cmd2 = atoi(data+1);
        if (cmd2==1) {  // calibrate gyro
          calculateGyroOffset(100);
        } else if (cmd2==2) {  // calibrate acc
          Serial << "Updating angle offset from " << angleOffset;
          angleOffset = filterAngle;
          Serial << " to " << angleOffset << endl;
          preferences.putFloat("angle_offset", angleOffset);
        }
        break;}
      case 'l':
        maxStepSpeed = atof(&data[1]);
        break;
      case 'n':
        gyroFilterConstant = atof(&data[1]);
        break;
      case 'w': {
        char cmd2 = data[1];
        char buf[63];
        uint8_t len;

        switch (cmd2) {
          case 'r':
            Serial.println("Rebooting...");
            ESP.restart();
            // pidParList.sendList(&wsServer);
            break;
          case 'l': // Send wifi networks to WS client
            sendWifiList();
            break;
          case 's': // Update WiFi SSID
            len = length-3;
            memcpy(buf, &data[2], len);
            buf[len] = 0;
            preferences.putBytes("wifi_ssid", buf, 63);
            break;
          case 'k': // Update WiFi key
            len = length-3;
            memcpy(buf, &data[2], len);
            buf[len] = 0;
            preferences.putBytes("wifi_key", buf, 63);
            break;
          case 'm': // WiFi mode (0=AP, 1=use SSID)
            Serial.println(atoi(&data[2]));
            preferences.putUInt("wifi_mode", atoi(&data[2]));
          }
        break;}
    }
  }
}

void sendWifiList(void) {
  char wBuf[200];
  uint8_t n;
  uint16_t pos = 2;

  wBuf[0] = 'w';
  wBuf[1] = 'l';

  Serial.println("Scan started");
  n = WiFi.scanNetworks();

  if (n>5) n = 5; // Limit to first 5 SSIDs

  // Make concatenated list, separated with commas
  for (uint8_t i=0; i<n; i++) {
    pos += sprintf(wBuf + pos, "%s,", WiFi.SSID(i).c_str());
  }
  wBuf[pos-1] = 0;

  Serial.println(wBuf);
  wsServer.sendTXT(0, wBuf);
}

void calculateGyroOffset(uint8_t nSample) {
  int32_t sumX = 0, sumY = 0, sumZ = 0;
  int16_t x, y, z;

  for (uint8_t i=0; i<nSample; i++) {
    imu.getRotation(&x, &y, &z);
    sumX += x;
    sumY += y;
    sumZ += z;
    delay(5);
  }

  gyroOffset[0] = sumX/nSample;
  gyroOffset[1] = sumY/nSample;
  gyroOffset[2] = sumZ/nSample;

  for (uint8_t i=0; i<3; i++) {
    char buf[16];
    sprintf(buf, "gyro_offset_%u", i);
    preferences.putShort(buf, gyroOffset[i]);
  }

  Serial << "New gyro calibration values: " << gyroOffset[0] << "\t" << gyroOffset[1] << "\t" << gyroOffset[2] << endl;
}

void readSensor() {
  int16_t ax, ay, az, gx, gy, gz;
  float deltaGyroAngle;

  imu.getMotion6(&ax, &ay, &az, &gx, &gy, &gz);

  // accAngle = atan2f((float) ax, (float) az) * 180.0/M_PI;
  // deltaGyroAngle = -((float)((gy - gyroOffset[1])) / GYRO_SENSITIVITY) * dT * gyroGain;
    accAngle = atan2f((float) ay, (float) az) * 180.0/M_PI - angleOffset;
    deltaGyroAngle = ((float)((gx - gyroOffset[0])) / GYRO_SENSITIVITY) * dT * gyroGain;

  filterAngle = gyroFilterConstant * (filterAngle + deltaGyroAngle) + (1 - gyroFilterConstant) * (accAngle);

  // Serial << ay/1000.0 << "\t" << az/1000.0 << "\t" << accAngle << "\t" << filterAngle << endl;
}

void initSensor(uint8_t n) {
  float gyroFilterConstantBackup = gyroFilterConstant;
  gyroFilterConstant = 0.8;
  for (uint8_t i=0; i<n; i++) {
    readSensor();
  }
  gyroFilterConstant = gyroFilterConstantBackup;

}

void setMicroStep(uint8_t uStep) {
  // input:                     1 2 4 8 16 32
  // uStep table corresponds to 0 1 2 3 4  5  in binary on uStep pins
  // So, we need to take the log2 of input
  uint8_t uStepPow = 0;
  while (uStep >>= 1) uStepPow++;

  digitalWrite(motUStepPin1, uStepPow&0x01);
  digitalWrite(motUStepPin2, uStepPow&0x02);
  digitalWrite(motUStepPin3, uStepPow&0x04);
}
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

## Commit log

2021-04-16 pcb and body
    [pendulumRobotModule-B_Cu.gbl, pendulumRobotModule-B_Mask.gbs, pendulumRobotModule-B_Paste.gbp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]
2021-05-15 motor_test and gcode
    [frameA1_mirror.stl, untitled.blend]
